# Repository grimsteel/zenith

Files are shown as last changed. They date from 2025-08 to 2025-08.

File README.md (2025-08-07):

# zenith

> A low cost USB-based FPV receiver/ground station

This was created to be used with [astra](https://github.com/TheScientist101/astra), a low cost FPV drone.

It features:
- A Seeed Studio RP2040 
- An RX5808

Inspired by the [rx5808-pro-diversity](https://github.com/sheaivey/rx5808-pro-diversity)

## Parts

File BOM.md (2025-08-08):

# General Component List

- **RX5808**: 5.8GHz receiver. Needs to have the SPI mod in order to be SPI-controllable
- **SMA connector**:
  - **RP SMA** = reverse polarity. The polarity of the antenna connector and the PCB connector just need to be opposite
- **MCU**: Anything works; I'm using an XIAO RP2040
- **Antenna**: Has to be 5.8GHz. The drone antenna is a dipole, so the circular one I have now isn't perfect. 
- **Video Out**: TBD. Ideally I would have a capture circuit on the PCB but that may be too difficult

# BOM

| Name | Quantity | Link | Total Price |
| - | - | - | - |
| SMA Connector | 1 | [AliExpress](https://www.aliexpress.com/item/3256804056009500.html) | $1.39 |
| 5.8GHz RHCP Antenna | 1 | [AliExpress](https://www.aliexpress.com/item/3256803558054206.html) | $4.34 |
| RX5808 5.8GHz receiver module | 1 | [AliExpress](https://www.aliexpress.com/item/3256808477588223.html) | $23.01 |
| XIAO RP2040 | 1 | Bin | $0.00 |
| I2C OLED | 1 | Already have | $0.00 |

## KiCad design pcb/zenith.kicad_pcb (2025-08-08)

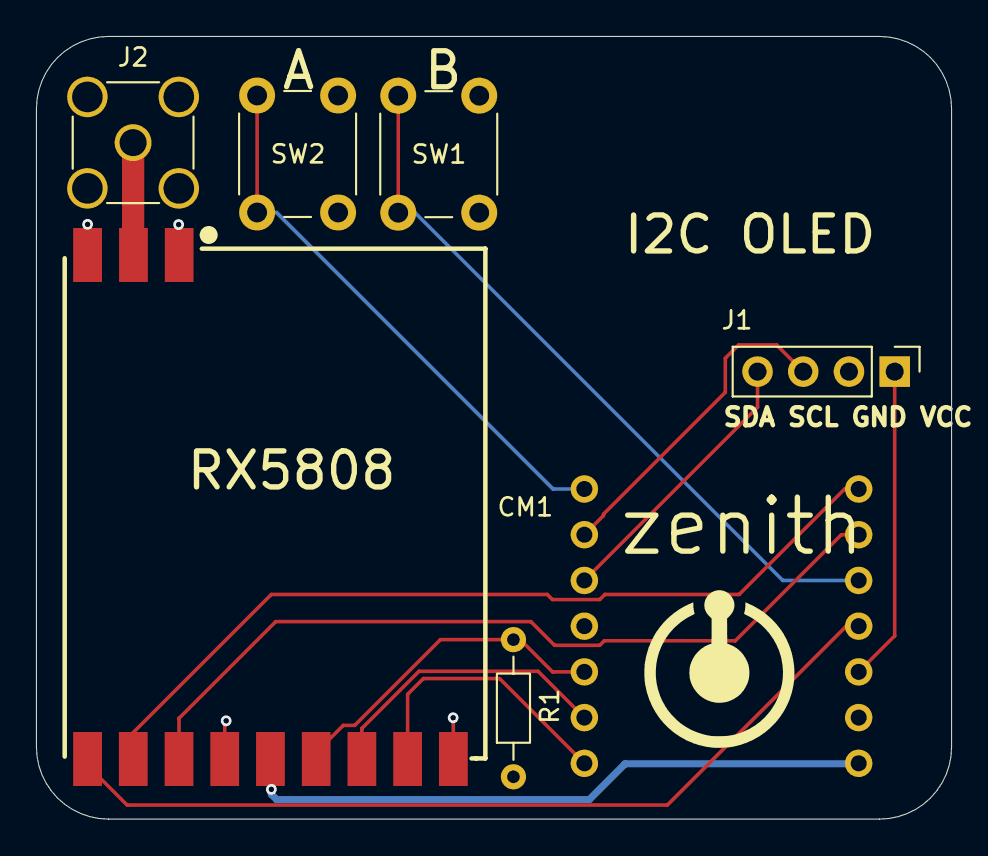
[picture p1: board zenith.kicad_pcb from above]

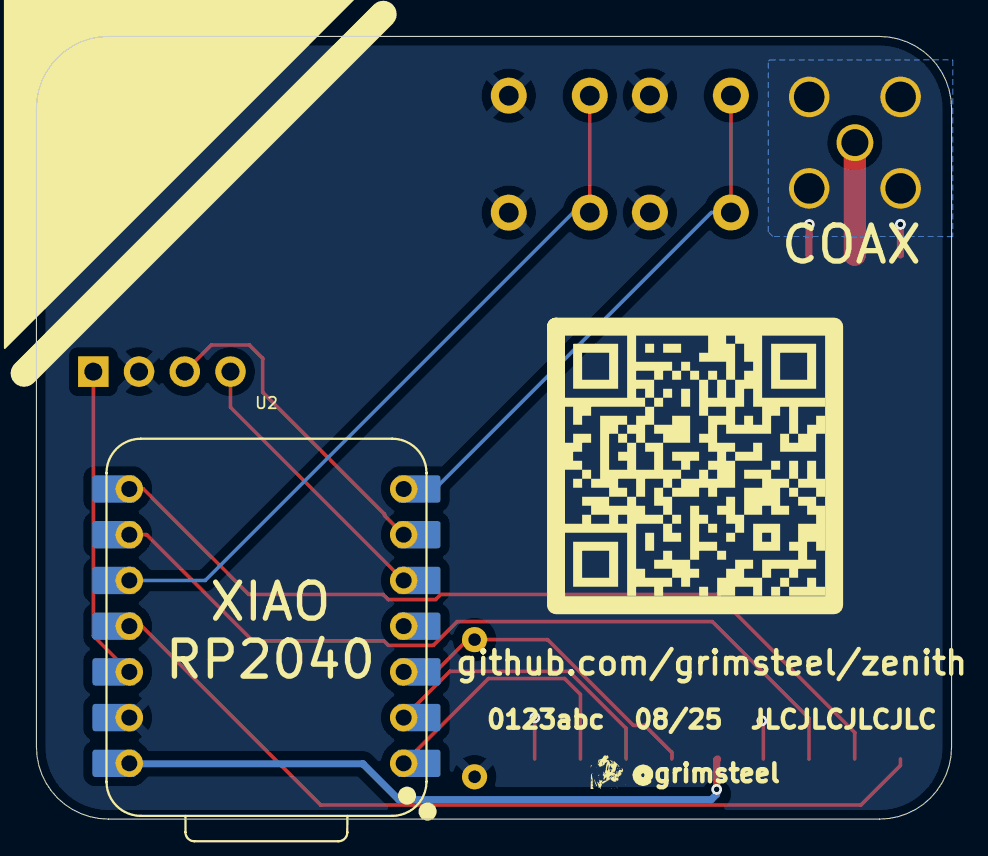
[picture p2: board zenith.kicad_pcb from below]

Board: 2 copper layers, 50.8 x 43.5 mm, 8 parts (2 on the bottom side), 14 nets.

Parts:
CM1: RX5808; COMM-SMD_12P_RX5808
J1: Conn_01x04_Pin; PinHeader_1x04_P2.54mm_Vertical
J2: Conn_Coaxial; SMA_Amphenol_901-144_Vertical
QR*****: https://github.com/grimsteel/zenith; qrcode
R1: 100k; R_Axial_DIN0204_L3.6mm_D1.6mm_P7.62mm_Horizontal
SW1, SW2: SW_Push; SW_PUSH_6mm
U2: XIAO-RP2040-DIP

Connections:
+3.3V: J1.1, U2.12 (3V3)
+5V: CM1.8 (+5V), U2.14 (VBUS)
ANT: CM1.2 (ANT), J2.1 (In)
AUDIO: CM1.10 (A6.5M), U2.2 (GPIO27/ADC1/A1)
BTN1: SW1.1, U2.10 (GPIO4/MISO)
BTN2: SW2.1, U2.7 (GPIO0/TX)
GND: CM1.1 (GND), CM1.3 (GND), CM1.7 (GND), CM1.12 (GND), J1.2, J2.2 (Ext), R1.1, SW1.2, SW2.2, U2.13 (GND)
MOSI: CM1.4 (CH1), U2.11 (GPIO3/MOSI)
RSSI: CM1.9 (RSSI), R1.2, U2.3 (GPIO28/ADC2/A2)
RX_CS: CM1.5 (CH2), U2.8 (GPIO1/RX)
SCK: CM1.6 (CH3), U2.9 (GPIO2/SCK)
SCL: J1.3, U2.6 (GPIO7/SCL)
SDA: J1.4, U2.5 (GPIO6/SDA)
VIDEO: CM1.11 (VIDEO), U2.1 (GPIO26/ADC0/A0)

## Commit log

2025-08-07 bom: add basic bom
2025-08-08 pcb: initial schematic + pcb
    [zenith.kicad_pcb, zenith.kicad_sch]
